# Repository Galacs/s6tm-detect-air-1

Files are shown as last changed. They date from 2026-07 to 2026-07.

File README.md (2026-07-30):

# S6TM Detect air 1

Air module 1 for the detect series with various co2 and mox air sensors

## IC List

- STM32F103C8T6 (Main MCU)
- HT7533 (MCU 3v3 LDO)
- HTU21D (Temperature and humidity)
- MiCS-5524 (MOX air sensor)
- S88 (CO2 NDIR sensor)
- ENS160 (MOX Sensor)
- SGP41 (MOX Sensors)
- SCD41 ("NDIR" co2 sensor)
- LMC6482 (op amp)
- SN65HVD230DR (CAN transceiver)
- LM73100 (+5V input protection)

## Top preview



## Preview 3d render



## Pin definitions

```c
#define I2C_SCL_PIN PB6
#define I2C_SDA_PIN PB7

#define RS1_PIN PA5
#define RS2_PIN PA6

#define CAN_RX_PIN PB8
#define CAN_RX_PIN  PB9

#define S88_TX_PIN PA10
#define S88_RX_PIN PA9

#define ENS160_INT_PIN PA15
```

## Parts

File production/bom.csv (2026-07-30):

Designator | Footprint | Quantity | Value | LCSC Part #
C1, C15, C16, C18, C20, C4 | 0402 | 6 | 1u | C52923
C10, C11, C12, C13, C14, C17, C19, C22, C3, C6 | 0402 | 10 | 0u1 | C307331
C2, C5, C7 | 0805 | 3 | 10u | C440198
C21, C23, C24 | 0805 | 3 | 22u | C45783
C8, C9 | 0603 | 2 | 20p | C1648
D1, D2, D3, D4, D5 | Diode_DFN1006 | 5 | H5VU10U | C22395519
D7 | 0805 | 1 | YELLOW | C2296
D8 | D_SMA | 1 | SMAJ12A | C19077531
D9 | 0805 | 1 | GREEN | C2297
FB1 | 0805 | 1 | 600Ω@100M | C81034
J6 | PinHeader_2x04_P2.54mm_Horizontal | 1 | Conn_01x08
R1 | 0402 | 1 | 100 | C25076
R10, R13 | 0402 | 2 | 5k1 | C25905
R11 | 0402 | 1 | 1k | C11702
R12 | 0402 | 1 | 2k | C4109
R2 | 0603 | 1 | 33 | C23140
R5, R6, R7 | 0402 | 3 | 10k | C25744
R8 | 0603 | 1 | 560 | C23204
R9 | 1206 | 1 | 120 | C17909
SW1, SW2 | SW_SPST_TS-1088-xR020 | 2 | SW_Push | C720477
U1 | Crystal_SMD_3225-4Pin_3.2x2.5mm | 1 | SYS1002-H2 | C5184223
U2 | Sensortech_MiCS_5x7mm_P1.25mm | 1 | MiCS-5524 | C3659348
U3 | SOIC-8_3.9x4.9mm_P1.27mm | 1 | LMC6482 | C95583
U4 | SOT-89-3 | 1 | HT753-1 | C14289
U5 | SOIC-8_3.9x4.9mm_P1.27mm | 1 | SN65HVD230 | C12084
U6 | LQFP-48_7x7mm_P0.5mm | 1 | STM32F103C8Tx | C8734
U7 | Texas_PWSON-N6 | 1 | HTU21 | C83479
U8 | Texas_RPW0010A_VQFN-HR-10_2x2mm_P0.5mm | 1 | LM73100 | C3210761
U9 | Sciosense_ENS160_LGA_9_3x3mm | 1 | ENS16x | C3659288
Y1 | Crystal_SMD_5032-2Pin_5.0x3.2mm | 1 | 8M | C115962

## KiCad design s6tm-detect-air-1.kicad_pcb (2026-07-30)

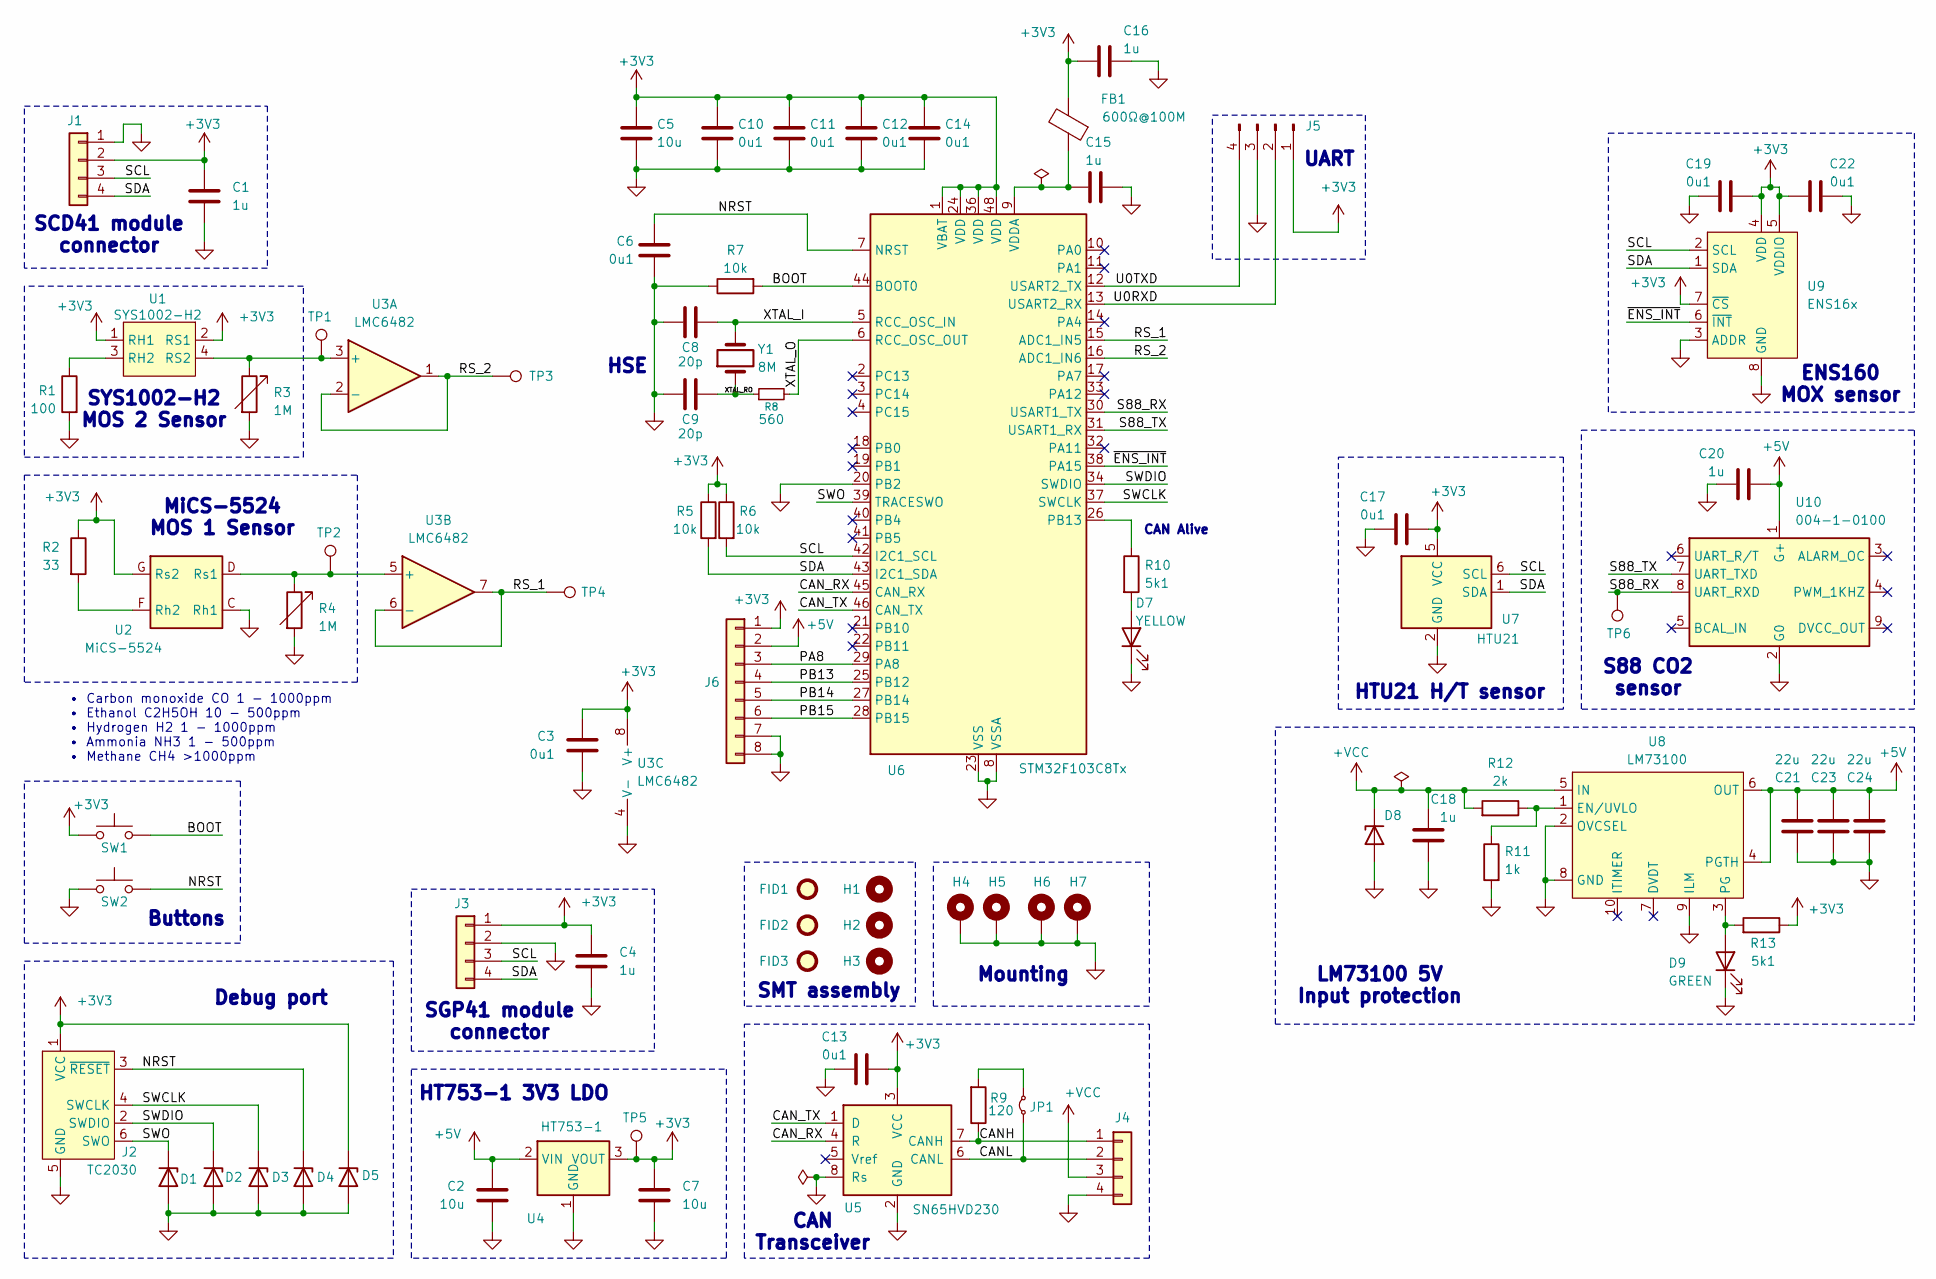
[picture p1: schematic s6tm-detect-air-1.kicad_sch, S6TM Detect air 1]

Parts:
C1, C4, C15, C16, C18, C20: 1u; C_0402_1005Metric; Manufacturer Part Number CL05A105KA5NQNC; JLCPCB Part # C52923
C2, C5, C7: 10u; C_0805_2012Metric; Manufacturer Part Number GRM21BR61H106KE43L; JLCPCB Part # C440198
C3, C6, C10, C11, C12, C13, C14, C17, C19, C22: 0u1; C_0402_1005Metric; Manufacturer Part Number CL05B104KB54PNC; JLCPCB Part # C307331
C8, C9: 20p; C_0603_1608Metric; Manufacturer Part Number CL10C200JB8NNNC; JLCPCB Part # C1648
C21, C23, C24: 22u; C_0805_2012Metric; Manufacturer Part Number CL21A226MAQNNNE; JLCPCB Part # C45783
D1, D2, D3, D4, D5: H5VU10U; Diode_DFN1006; Manufacturer Part Number H5VU10U; JLCPCB Part # C22395519
D7: YELLOW; LED_0805_2012Metric; Manufacturer Part Number KT-0805Y; JLCPCB Part # C2296
D8: SMAJ12A; D_SMA; Manufacturer Part Number SMAJ12A; JLCPCB Part # C19077531
D9: GREEN; LED_0805_2012Metric; Manufacturer Part Number KT-0805G; JLCPCB Part # C2297
FB1: 600Ω@100M; L_0805_2012Metric; Manufacturer Part Number MPZ2012S601ATD25; JLCPCB Part # C81034
FID1, FID2, FID3: Fiducial; Fiducial_1mm_Mask2mm
H1, H2, H3: MountingHole; ToolingHole_1.152mm
H4, H5, H6, H7: MountingHole_Pad; MountingHole_3.2mm_M3_Pad_Via
J1, J3: Conn_01x04; PinHeader_1x04_P2.54mm_Vertical
J2: TC2030; Tag-Connect_TC2030-IDC-NL_2x03_P1.27mm_Vertical
J4: Conn_01x04; JST_XH_S4B-XH-A-1_1x04_P2.50mm_Horizontal; Manufacturer Part Number S4B-XH-A-1(LF)(SN); JLCPCB Part # C163037
J5: Conn_01x04_Pin; PinHeader_1x04_P2.54mm_Vertical
J6: Conn_01x08; PinHeader_2x04_P2.54mm_Horizontal
JP1: Jumper_2_Small_Bridged; SolderJumper-2_P1.3mm_Open_RoundedPad1.0x1.5mm
R1: 100; R_0402_1005Metric; Manufacturer Part Number 0402WGF1000TCE; JLCPCB Part # C25076
R2: 33; R_0603_1608Metric; Manufacturer Part Number 0603WAF330JT5E; JLCPCB Part # C23140
R3, R4: 1M; Potentiometer_Bourns_3296W_Vertical
R5, R6, R7: 10k; R_0402_1005Metric; Manufacturer Part Number 0402WGF1002TCE; JLCPCB Part # C25744
R8: 560; R_0603_1608Metric; Manufacturer Part Number 0603WAF5600T5E; JLCPCB Part # C23204
R9: 120; R_1206_3216Metric; Manufacturer Part Number 1206W4F1200T5E; JLCPCB Part # C17909
R10, R13: 5k1; R_0402_1005Metric; Manufacturer Part Number 0402WGF5101TCE; JLCPCB Part # C25905
R11: 1k; R_0402_1005Metric; Manufacturer Part Number 0402WGF1001TCE; JLCPCB Part # C11702
R12: 2k; R_0402_1005Metric; Manufacturer Part Number 0402WGF2001TCE; JLCPCB Part # C4109
SW1, SW2: SW_Push; SW_SPST_TS-1088-xR020; Manufacturer Part Number TS-1088-AR02016; JLCPCB Part # C720477
TP1, TP2, TP3, TP4, TP5, TP6: TestPoint; TestPoint_Pad_D2.0mm
U1: SYS1002-H2; Crystal_SMD_3225-4Pin_3.2x2.5mm; Manufacturer Part Number SYS1002-H2; JLCPCB Part # C5184223
U2: MiCS-5524; Sensortech_MiCS_5x7mm_P1.25mm; Manufacturer Part Number MICS-5524; JLCPCB Part # C3659348
U3: LMC6482; SOIC-8_3.9x4.9mm_P1.27mm; Manufacturer Part Number LMC6482IMX/NOPB; JLCPCB Part # C95583
U4: HT753-1; SOT-89-3; Manufacturer Part Number HT7533-1; JLCPCB Part # C14289
U5: SN65HVD230; SOIC-8_3.9x4.9mm_P1.27mm; Manufacturer Part Number SN65HVD230DR; JLCPCB Part # C12084
U6: STM32F103C8Tx; LQFP-48_7x7mm_P0.5mm; Manufacturer Part Number STM32F103C8T6; JLCPCB Part # C8734
U7: HTU21; Texas_PWSON-N6; Manufacturer Part Number HTU21D; JLCPCB Part # C83479
U8: LM73100; Texas_RPW0010A_VQFN-HR-10_2x2mm_P0.5mm; Manufacturer Part Number LM73100RPWR; JLCPCB Part # C3210761
U9: ENS16x; Sciosense_ENS160_LGA_9_3x3mm; Manufacturer Part Number ENS160-BGLM; JLCPCB Part # C3659288
U10: 004-1-0100; Senseair_S8_Up
Y1: 8M; Crystal_SMD_5032-2Pin_5.0x3.2mm; Manufacturer Part Number X50328MSB2GI; JLCPCB Part # C115962

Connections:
+3V3: C1.2, C3.2, C4.2, C5.1, C7.1, C10.1, C11.1, C12.1, C13.1, C14.1, C16.1, C17.2, C19.1, C22.1, D5.1 (K), FB1.2, J1.2, J2.1 (VCC), J3.1, J5.1, J6.1, R2.1, R5.1, R6.1, R13.1, SW1.1, TP5.1 (1_1), U1.1 (RH1), U1.2 (RS1), U2.G (Rs2), U3.8 (V+), U4.3 (VOUT), U5.3 (VCC), U6.1 (VBAT), U6.24 (VDD), U6.36 (VDD), U6.48 (VDD), U7.5 (VCC), U9.4 (VDD), U9.5 (VDDIO), U9.7 (~CS)
+5V: C2.1, C20.1, C21.2, C23.2, C24.2, J6.2, U4.2 (VIN), U8.4 (PGTH), U8.6 (OUT), U10.1 (G+)
+VCC: C18.2, D8.1 (K), J4.3, R12.2, U8.5 (IN)
/BOOT: R7.2, SW1.2, U6.44 (BOOT0)
/CANH: J4.1, R9.1, U5.7 (CANH)
/CANL: J4.2, JP1.1 (A), U5.6 (CANL)
/CAN_RX: U5.4 (R), U6.45 (CAN_RX)
/CAN_TX: U5.1 (D), U6.46 (CAN_TX)
/NRST: C6.1, D4.1 (K), J2.3 (~RESET), SW2.2, U6.7 (NRST)
/PA8: J6.3, U6.29 (PA8)
/PB13: J6.4, U6.25 (PB12)
/PB14: J6.5, U6.27 (PB14)
/PB15: J6.6, U6.28 (PB15)
/RS_1: TP4.1 (1_1), U3.6 (-), U3.7, U6.15 (ADC1_IN5)
/RS_2: TP3.1 (1_1), U3.1, U3.2 (-), U6.16 (ADC1_IN6)
/S88_RX: TP6.1 (1_1), U6.30 (USART1_TX), U10.8 (UART_RXD)
/S88_TX: U6.31 (USART1_RX), U10.7 (UART_TXD)
/SCL: J1.3, J3.3, R6.2, U6.42 (I2C1_SCL), U7.6 (SCL), U9.2 (SCL)
/SDA: J1.4, J3.4, R5.2, U6.43 (I2C1_SDA), U7.1 (SDA), U9.1 (SDA)
/SWCLK: D3.1 (K), J2.4 (SWCLK), U6.37 (SWCLK)
/SWDIO: D2.1 (K), J2.2 (SWDIO), U6.34 (SWDIO)
/SWO: D1.1 (K), J2.6 (SWO), U6.39 (TRACESWO)
/U0RXD: J5.2, U6.13 (USART2_RX)
/U0TXD: J5.4, U6.12 (USART2_TX)
/XTAL_I: C8.1, U6.5 (RCC_OSC_IN), Y1.2
/XTAL_O: R8.2, U6.6 (RCC_OSC_OUT)
/XTAL_RO: C9.1, R8.1, Y1.1
/~ENS_INT: U6.38 (PA15), U9.6 (~INT)
GND: C1.1, C2.2, C3.1, C4.1, C5.2, C6.2, C7.2, C8.2, C9.2, C10.2, C11.2, C12.2, C13.2, C14.2, C15.2, C16.2, C17.1, C18.1, C19.2, C20.2, C21.1, C22.2, C23.1, C24.1, D1.2 (A), D2.2 (A), D3.2 (A), D4.2 (A), D5.2 (A), D7.1 (K), D8.2 (A), D9.1 (K), H4.1 (1_1), H5.1 (1_1), H6.1 (1_1), H7.1 (1_1), J1.1, J2.5 (GND), J3.2, J4.4, J5.3, J6.7, J6.8, R1.2, R3.2, R4.2, R7.1, R11.2, SW2.1, U2.C (Rh1), U3.4 (V-), U4.1 (GND), U5.2 (GND), U5.8 (Rs), U6.8 (VSSA), U6.20 (PB2), U6.23 (VSS), U6.35 (VSS), U6.47 (VSS), U7.2 (GND), U8.2 (OVCSEL), U8.8 (GND), U8.9 (ILM), U9.3 (ADDR), U9.8 (GND), U9.9 (GND), U10.2 (G0)
unnamed: D7.2 (A), R10.2
unnamed: D9.2 (A), R13.2, U8.3 (PG)
unnamed: JP1.2 (B), R9.2
unnamed: R1.1, U1.3 (RH2)
unnamed: R3.1, TP1.1 (1_1), U1.4 (RS2), U3.3 (+)
unnamed: R2.2, U2.F (Rh2)
unnamed: R4.1, TP2.1 (1_1), U2.D (Rs1), U3.5 (+)
unnamed: R10.1, U6.26 (PB13)
unnamed: C15.1, FB1.1, U6.9 (VDDA)
unnamed: R11.1, R12.1, U8.1 (EN/UVLO)

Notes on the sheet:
CAN Transceiver
SCD41 module connector
Mounting
SYS1002-H2 MOS 2 Sensor
SMT assembly
MiCS-5524 MOS 1 Sensor
HTU21 H/T sensor
LM73100 5V Input protection
Buttons
SGP41 module connector
UART
• Carbon monoxide CO 1 - 1000ppm • Ethanol C2H5OH 10 - 500ppm • Hydrogen H2 1 - 1000ppm • Ammonia NH3 1 - 500ppm • Methane CH4 >1000ppm
HSE
ENS160 MOX sensor
S88 CO2 sensor
CAN Alive
Debug port
HT753-1 3V3 LDO

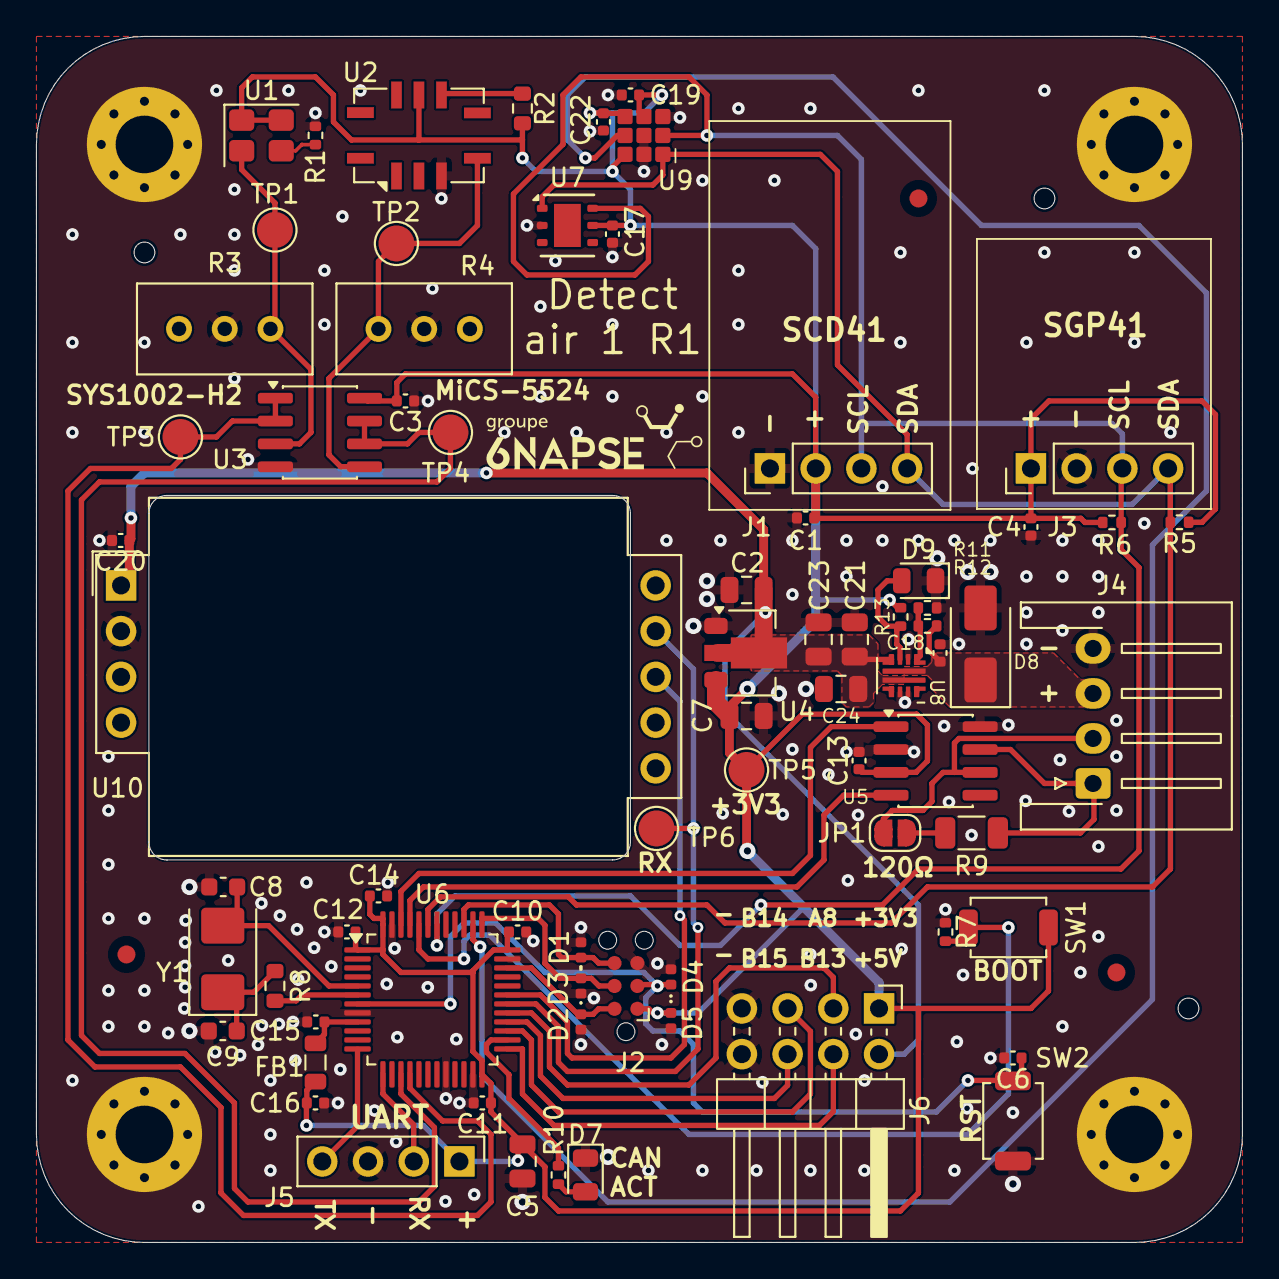
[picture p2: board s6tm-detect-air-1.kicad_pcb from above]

Board: 2 copper layers, 67.0 x 67.0 mm, 82 parts (0 on the bottom side), 39 nets.

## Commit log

2026-07-27 schem: import stm32f104 mcu
    [s6tm-detect-air-1.kicad_sch]
2026-07-27 schem: import HT753-1 3V3 LDO
    [s6tm-detect-air-1.kicad_sch]
2026-07-27 schem: add LM73100 5V Input protection
    [s6tm-detect-air-1.kicad_sch]
2026-07-27 schem: import can transceiver and connector
    [s6tm-detect-air-1.kicad_sch]
2026-07-27 schem: add boot/rst buttons
    [s6tm-detect-air-1.kicad_sch]
2026-07-27 schem: add MiCS-5524 MOS 1 Sensor
    [s6tm-detect-air-1.kicad_sch]
2026-07-27 schem: add SGP41 module connector
    [s6tm-detect-air-1.kicad_sch]
2026-07-27 schem: add SCD41 module connector
    [s6tm-detect-air-1.kicad_sch]
2026-07-28 schem: update mics-5524 sense load resistor
    [s6tm-detect-air-1.kicad_sch]
2026-07-28 schem: add senseair s88 co2 sensor
    [s6tm-detect-air-1.kicad_sch]
2026-07-28 schem: add SYS1002-H2 MOS 2 Sensor
    [s6tm-detect-air-1.kicad_sch]
2026-07-28 schem: add HTU21 H/T sensor
    [s6tm-detect-air-1.kicad_sch]
2026-07-29 schem: connect missing gpios
    [s6tm-detect-air-1.kicad_sch]
2026-07-29 schem: add no connects
    [s6tm-detect-air-1.kicad_sch]
2026-07-29 schem: add test points
    [s6tm-detect-air-1.kicad_sch]
2026-07-29 schem: run and fix erc
    [s6tm-detect-air-1.kicad_sch]
2026-07-29 schem: add missing footprints
    [s6tm-detect-air-1.kicad_sch]
2026-07-29 schem: add ENS160 footprint
    [s6tm-detect-air-1.kicad_sch]
2026-07-29 schem: fix potentiometer footprints
    [s6tm-detect-air-1.kicad_sch]
2026-07-29 schem: add ordering info to BOM
    [s6tm-detect-air-1.kicad_sch]
2026-07-29 schem: add title
    [s6tm-detect-air-1.kicad_sch]
2026-07-29 schem: renumber
    [s6tm-detect-air-1.kicad_sch]
2026-07-29 pcb: import 2 layer jlc stackup
    [s6tm-detect-air-1.kicad_pcb, s6tm-detect-air-1.kicad_sch]
2026-07-29 pcb: add missing 3dmodels
    [s6tm-detect-air-1.kicad_pcb]
2026-07-29 pcb: initial sectionning
    [s6tm-detect-air-1.kicad_pcb]
2026-07-29 pcb: add can and efuse layout
    [s6tm-detect-air-1.kicad_pcb]
2026-07-29 pcb: add mox layout
    [s6tm-detect-air-1.kicad_pcb]
2026-07-29 pcb: add pwr layout
    [s6tm-detect-air-1.kicad_pcb, s6tm-detect-air-1.kicad_sch]
2026-07-29 pcb: add ens160 layout
    [s6tm-detect-air-1.kicad_pcb]
2026-07-29 pcb: add swd layout
    [s6tm-detect-air-1.kicad_pcb]
2026-07-29 pcb: add module layout
    [s6tm-detect-air-1.kicad_pcb, s6tm-detect-air-1.kicad_sch]
2026-07-29 pcb: add stm32 layout
    [s6tm-detect-air-1.kicad_pcb]
2026-07-29 pcb: add initial layout
    [s6tm-detect-air-1.kicad_pcb]
2026-07-29 schem: add mounting & tooling holes
    [s6tm-detect-air-1.kicad_sch]
2026-07-29 pcb: add board outline
    [s6tm-detect-air-1.kicad_pcb]
2026-07-29 pcb: add gnd planes
    [s6tm-detect-air-1.kicad_pcb]
2026-07-29 pcb: add gnd vias
    [s6tm-detect-air-1.kicad_pcb]
2026-07-29 pcb: add drill/place origin
    [s6tm-detect-air-1.kicad_pcb]
2026-07-29 pcb/schem: add spare gpios header
    [s6tm-detect-air-1.kicad_pcb, s6tm-detect-air-1.kicad_sch]
2026-07-29 pcb: add crystal routing
    [s6tm-detect-air-1.kicad_pcb]
2026-07-29 pcb: add swd routing
    [s6tm-detect-air-1.kicad_pcb]
2026-07-29 pcb: add can routing
    [s6tm-detect-air-1.kicad_pcb]
2026-07-29 pcb: add uart routing
    [s6tm-detect-air-1.kicad_pcb]
2026-07-29 pcb: add gpios routing
    [s6tm-detect-air-1.kicad_pcb, s6tm-detect-air-1.kicad_sch]
2026-07-29 pcb: add status led routing
    [s6tm-detect-air-1.kicad_pcb]
2026-07-29 pcb: add efuse routing
    [s6tm-detect-air-1.kicad_pcb]
2026-07-29 pcb: add s88 cutout
    [s6tm-detect-air-1.kicad_pcb]
2026-07-29 pcb: add mox sensors routing
    [s6tm-detect-air-1.kicad_pcb]
2026-07-29 pcb: add i2c routing
    [s6tm-detect-air-1.kicad_pcb]
2026-07-29 pcb: add +3V3 pwr routing
    [s6tm-detect-air-1.kicad_pcb]
2026-07-29 pcb: add +5V pwr routing
    [s6tm-detect-air-1.kicad_pcb]
2026-07-29 pcb: add boot routing
    [s6tm-detect-air-1.kicad_pcb]
2026-07-29 pcb: add stitching vias
    [s6tm-detect-air-1.kicad_pcb]
2026-07-29 pcb(silk): clean up reference designators
    [s6tm-detect-air-1.kicad_pcb]
2026-07-29 pcb: add title
    [s6tm-detect-air-1.kicad_pcb]
2026-07-29 pcb(silk): add title
    [s6tm-detect-air-1.kicad_pcb]
2026-07-29 pcb(silk): edit user text
    [s6tm-detect-air-1.kicad_pcb]
2026-07-29 pcb(silk): finish user txt
    [s6tm-detect-air-1.kicad_pcb]
2026-07-30 pcb: fix sys1002 mox pins
    [s6tm-detect-air-1.kicad_pcb]
2026-07-30 generate production files
    [bom.csv, designators.csv, positions.csv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]
2026-07-30 pcb: fix s88 rx/tx orientation
    [s6tm-detect-air-1.kicad_pcb, s6tm-detect-air-1.kicad_sch]
